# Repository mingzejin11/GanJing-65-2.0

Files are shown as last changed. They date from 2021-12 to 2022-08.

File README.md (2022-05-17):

# GanJing 65 rev 2.0
**A 65% keyboard with a rotary encoder, OLED screen and USB-c. Made using the Elite-c and through-hole components for easy soldering.**

[Bill of materials](https://octopart.com/bom-tool/jvwkTsDN)

## Layout options
The GanJing 65 PCB is hotswappable, supports ISO layouts, stepped caps lock, split right shift, and split spacebar options. There is also a soldered PCB available.

### Supported hotswap layouts
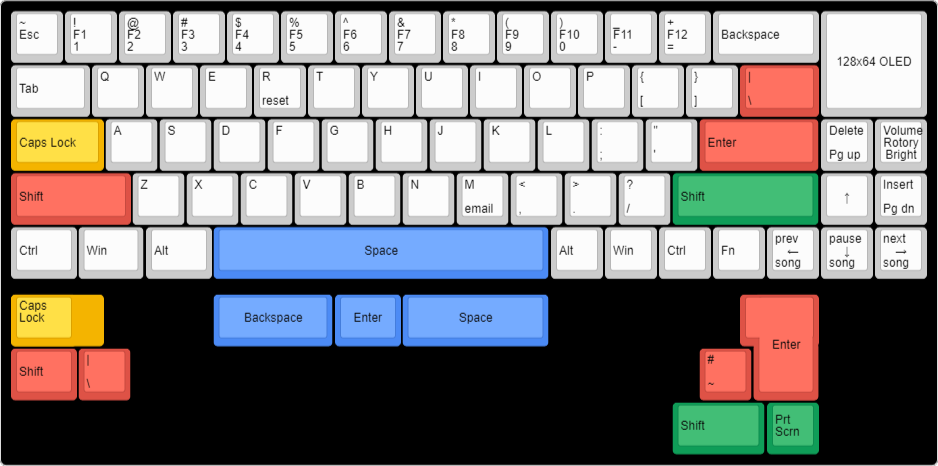
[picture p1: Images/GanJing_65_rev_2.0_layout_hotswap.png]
GanJing-65-2.0


## Hotswap PCB layout
### Front
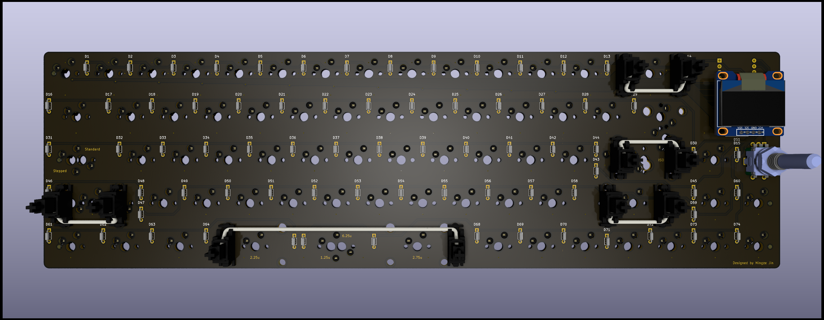
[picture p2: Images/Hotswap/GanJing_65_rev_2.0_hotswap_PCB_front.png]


### Back
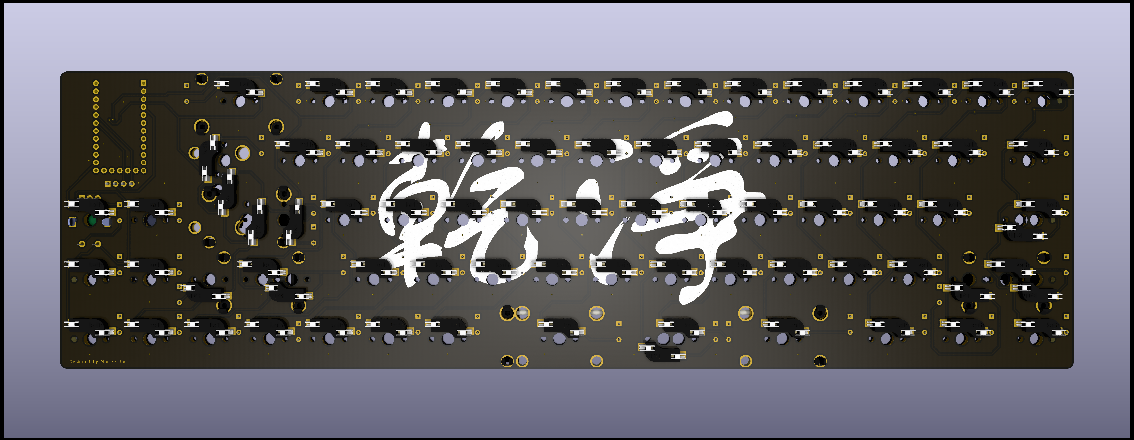
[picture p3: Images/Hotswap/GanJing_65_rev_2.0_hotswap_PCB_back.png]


## Hotswap PCB layout with exposed traces
### Front ANSI
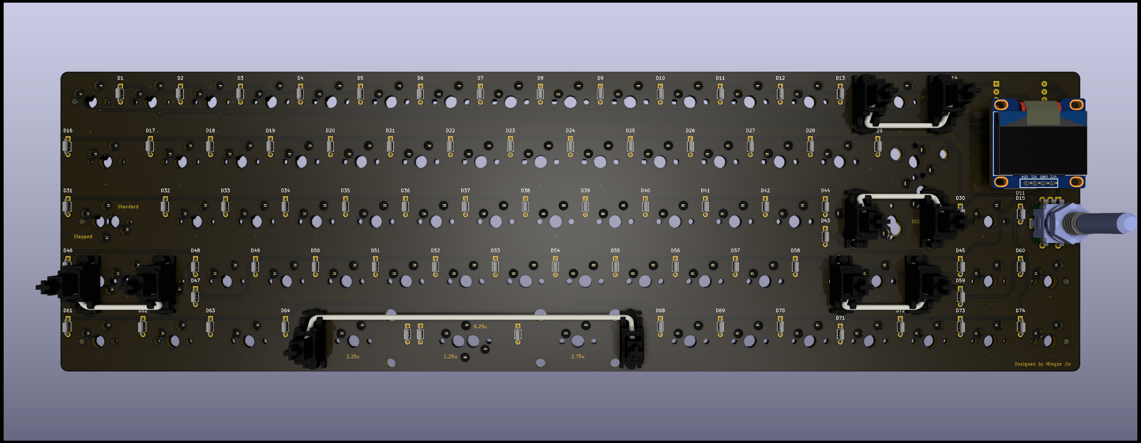
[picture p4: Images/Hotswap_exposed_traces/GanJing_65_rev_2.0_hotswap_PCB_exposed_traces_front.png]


### Front ISO and split spacebar
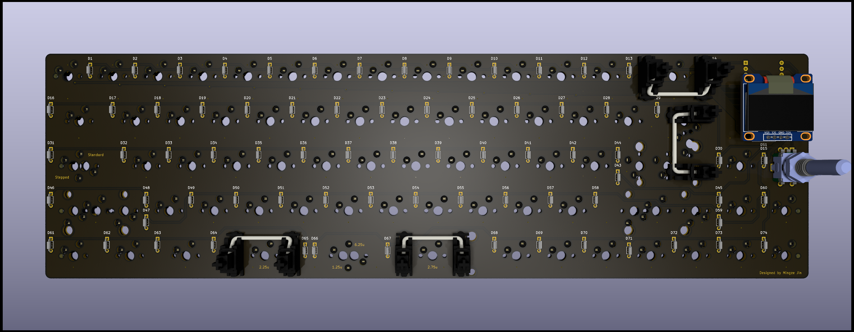
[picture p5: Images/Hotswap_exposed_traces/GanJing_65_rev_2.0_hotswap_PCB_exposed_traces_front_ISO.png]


### Back
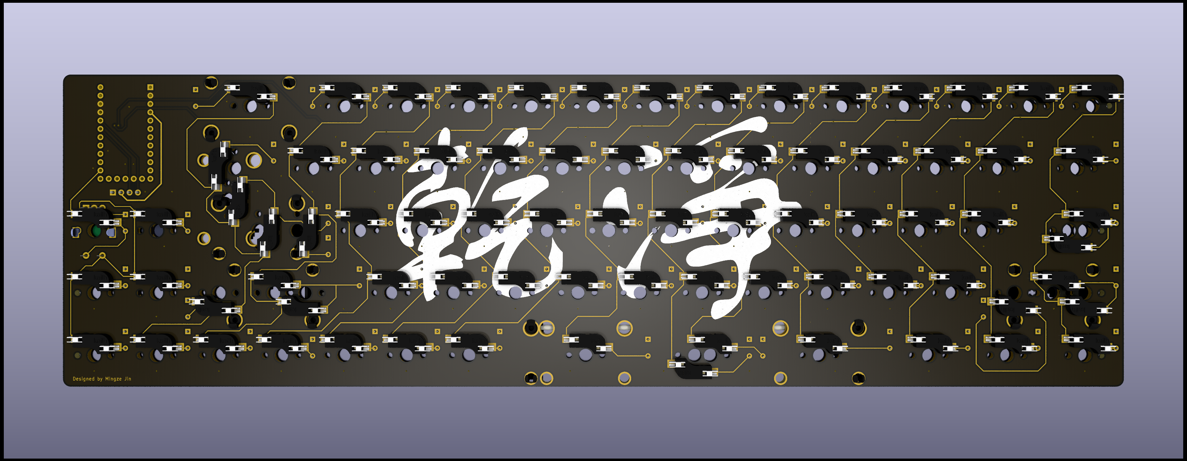
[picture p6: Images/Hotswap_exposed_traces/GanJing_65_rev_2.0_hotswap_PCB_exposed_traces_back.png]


### Supported solder layouts
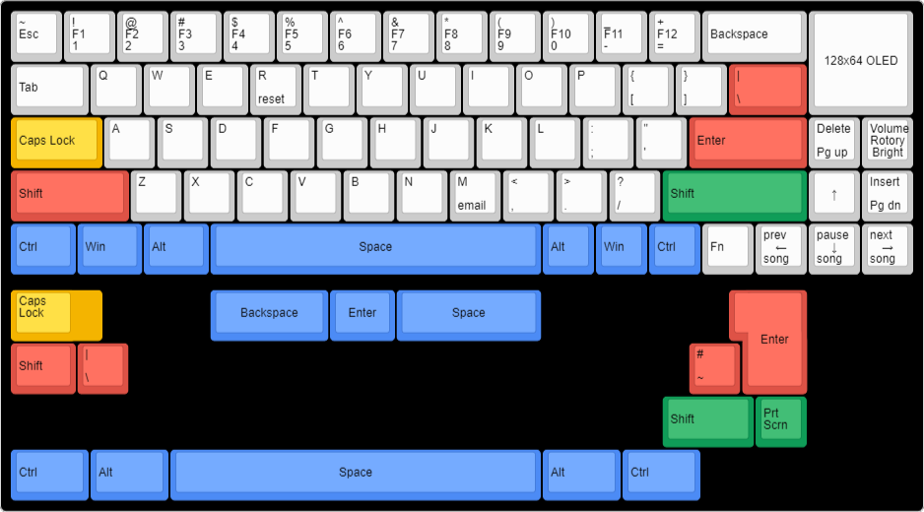
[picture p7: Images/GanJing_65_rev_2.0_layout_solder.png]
GanJing-65-2.0


## Solder PCB layout
### Front
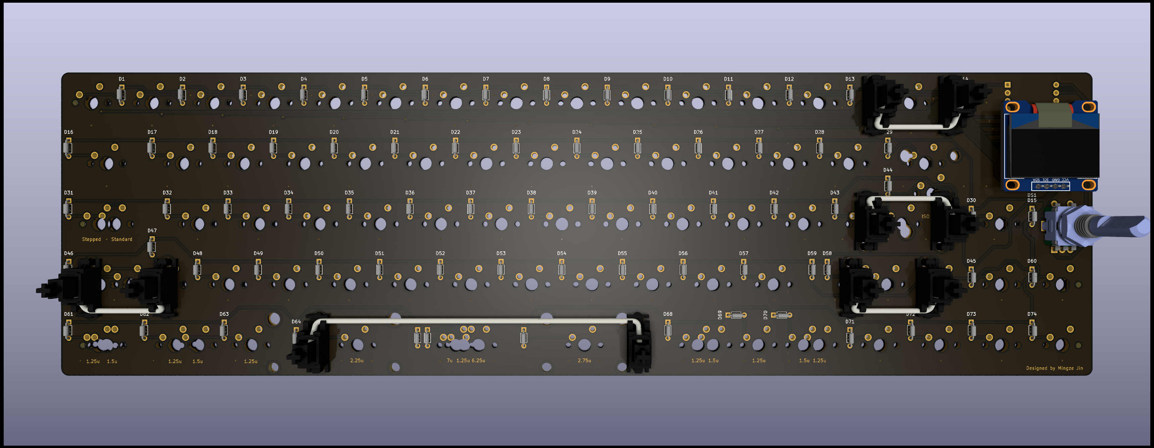
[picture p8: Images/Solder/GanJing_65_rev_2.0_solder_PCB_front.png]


### Front ISO and 7u spacebar
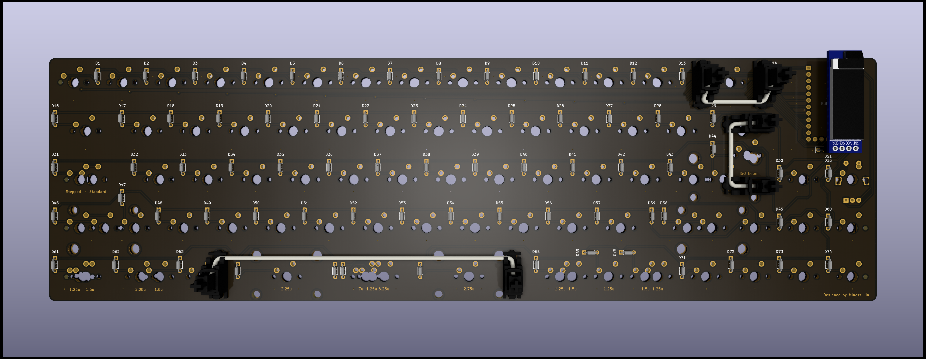
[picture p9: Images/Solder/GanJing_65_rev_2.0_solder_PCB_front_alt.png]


### Back
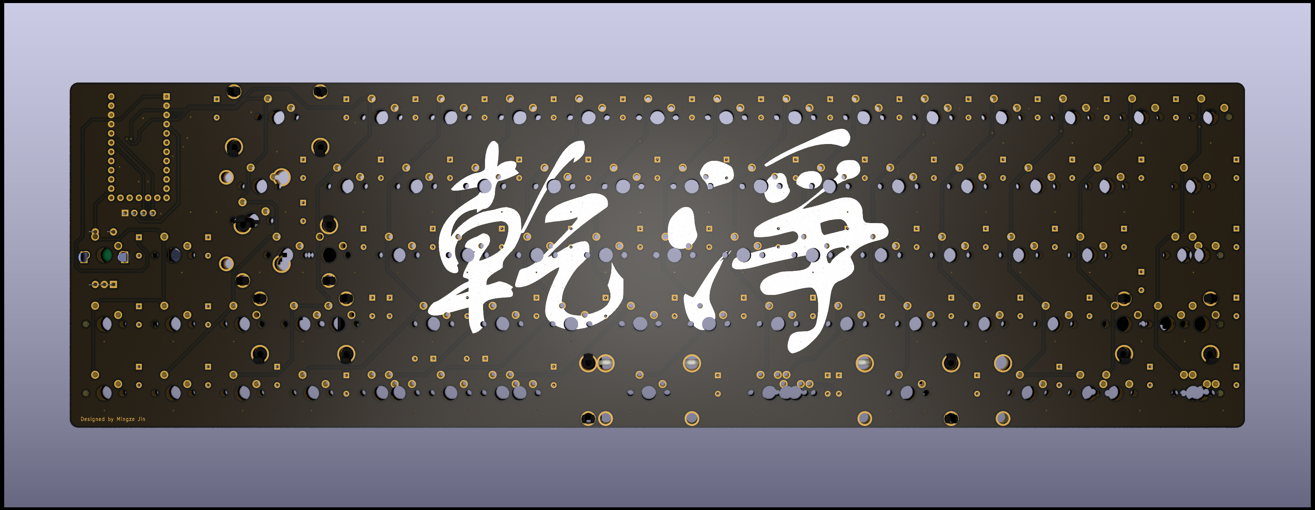
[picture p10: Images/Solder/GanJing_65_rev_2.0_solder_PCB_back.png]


## Schematic
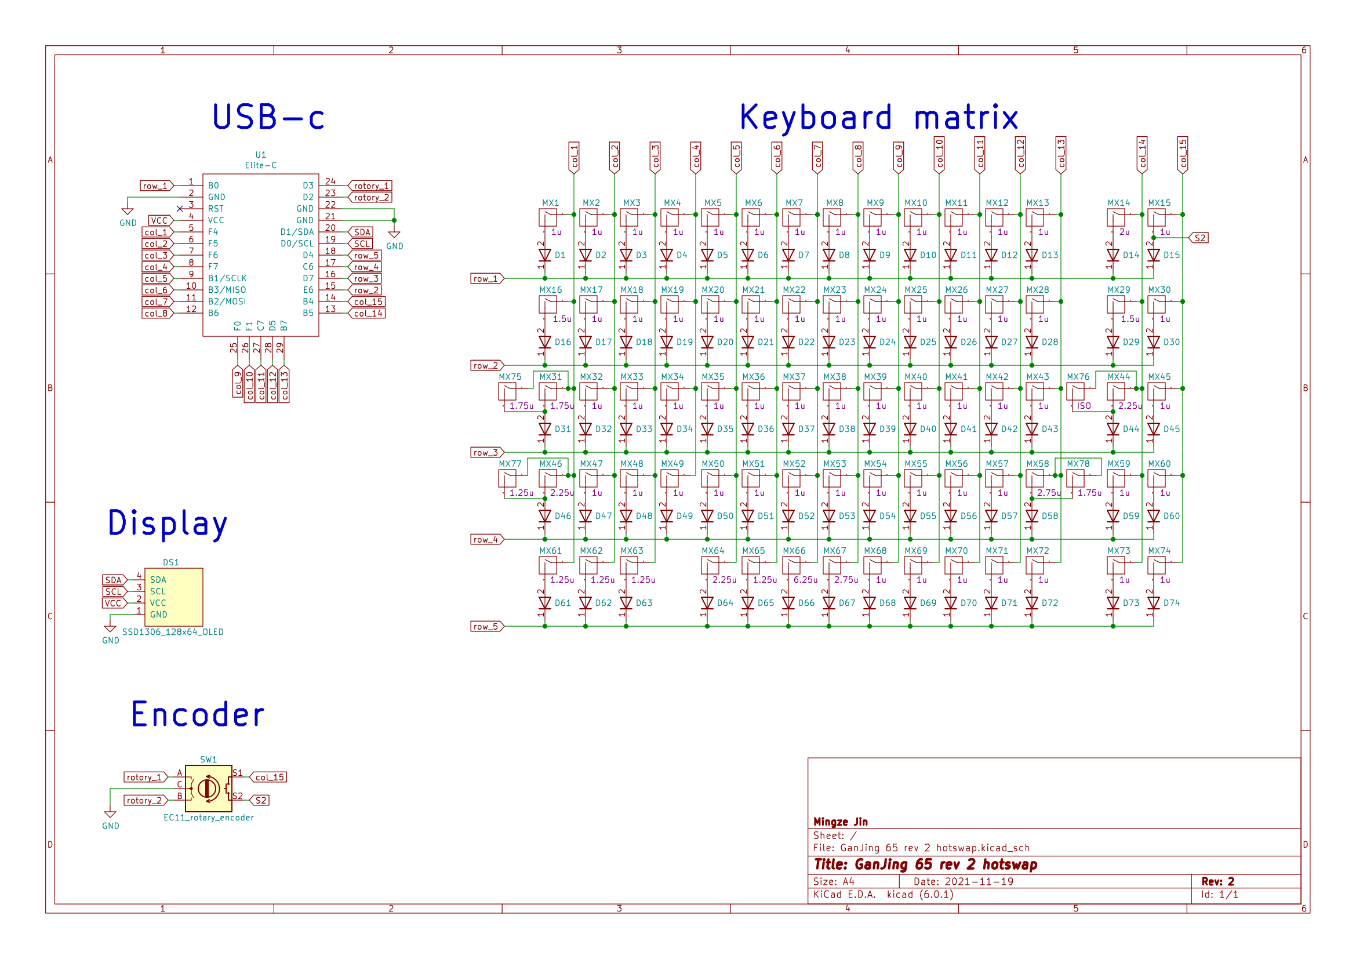
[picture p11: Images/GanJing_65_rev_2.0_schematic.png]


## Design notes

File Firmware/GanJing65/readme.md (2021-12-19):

# GanJing 70

GanJing 70

A 70% keyboard that can be assembled with only through hole components, including usb type-c and the Elite-C V4

* Keyboard Maintainer: [mingzejin11](https://github.com/mingzejin11)
* Hardware Supported: GanJing 70, atmega32u4
* Hardware Availability: [GitHub](https://github.com/mingzejin11/GanJing-65-2.0)

Make example for this keyboard (after setting up your build environment):

    make mingzejin11/GanJing65:default

Flashing example for this keyboard:

    make mingzejin11/GanJing65:default:flash

See the [build environment setup](https://docs.qmk.fm/#/getting_started_build_tools) and the [make instructions](https://docs.qmk.fm/#/getting_started_make_guide) for more information. Brand new to QMK? Start with our [Complete Newbs Guide](https://docs.qmk.fm/#/newbs).

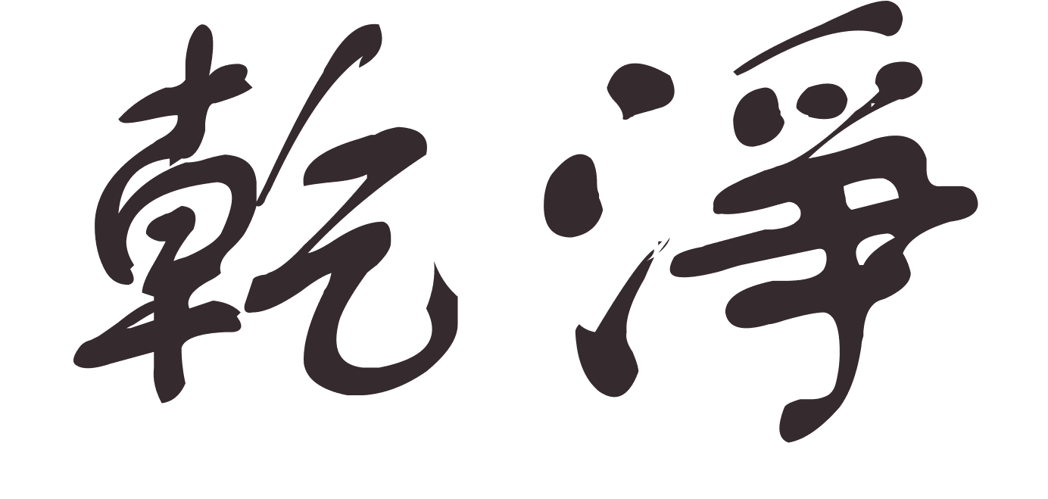
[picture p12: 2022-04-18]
Images/GanJing characters.png

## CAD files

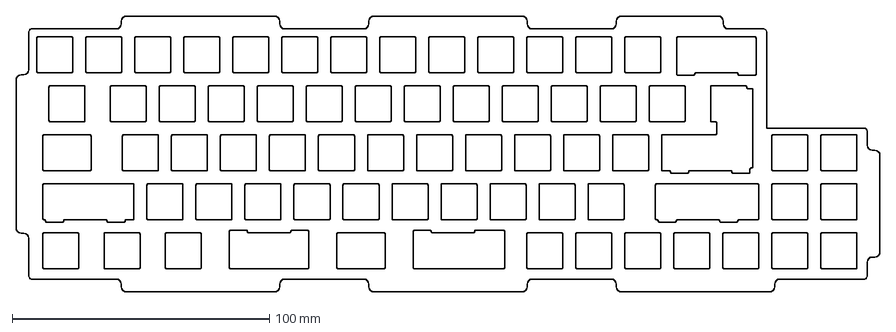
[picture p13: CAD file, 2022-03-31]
Case/Plate/GanJing 70 plate rev 2.dxf
335.8 x 107.2 mm

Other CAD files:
Case/GanJing 70 top.dwg
Case/4 3mm.dwg
Case/GanJing 70 plate rev 2.dwg
Case/2 4.5mm.dwg
Case/GanJing 70 middle gasket.dwg
Case/GanJing 70 middle open.dwg
Case/3 3mm.dwg
Case/GanJing 70 bottom.dwg
Case/1 3mm.dwg
Case/GanJing 70 middle closed.dwg

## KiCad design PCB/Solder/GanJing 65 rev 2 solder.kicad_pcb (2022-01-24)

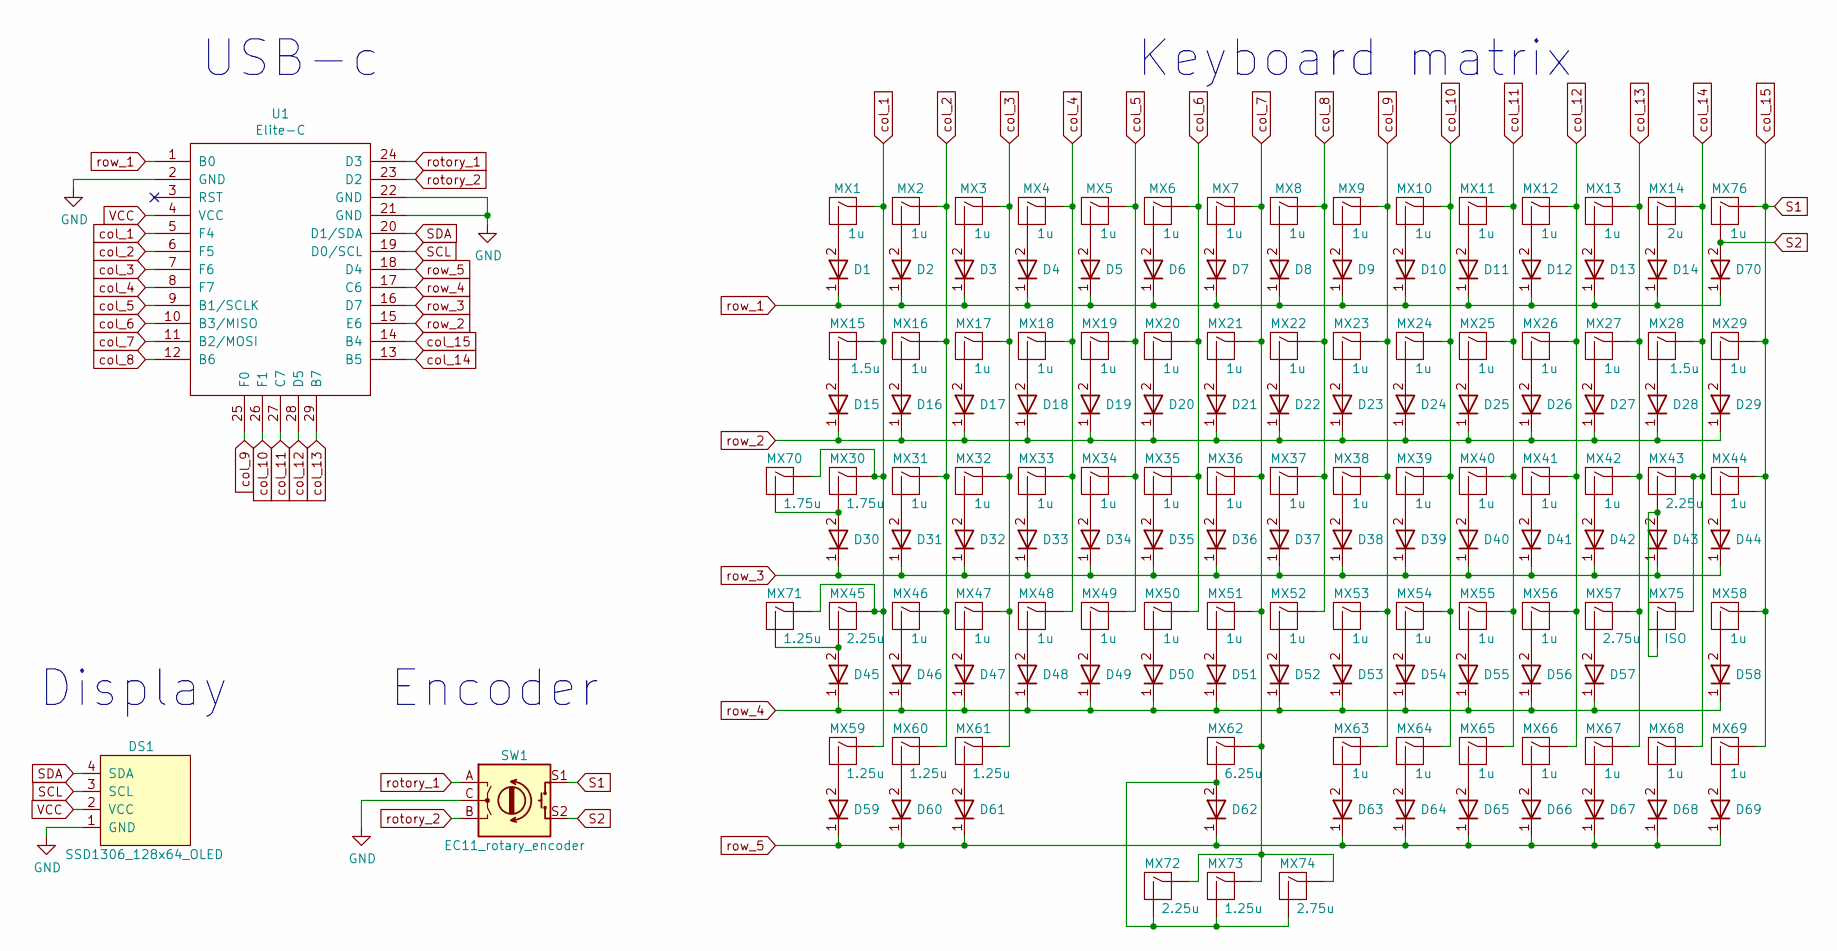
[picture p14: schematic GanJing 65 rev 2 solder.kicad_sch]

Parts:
D1, D2, D3, D4, D5, D6, D7, D8, D9, D10, D11, D12, D13, D14, D15, D16, D17, D18, D19, D20, D21, D22, D23, D24, D25, D26, D27, D28, D29, D30, D31, D32, D33, D34, D35, D36, D37, D38, D39, D40, D41, D42, D43, D44, D45, D46, D47, D48, D49, D50, D51, D52, D53, D54, D55, D56, D57, D58, D59, D60, D61, D62, D63, D64, D65, D66, D67, D68, D69, D70: 1N4148TR_diode
DS1: SSD1306_128x64_OLED
MX1, MX2, MX3, MX4, MX5, MX6, MX7, MX8, MX9, MX10, MX11, MX12, MX13, MX16, MX17, MX18, MX19, MX20, MX21, MX22, MX23, MX24, MX25, MX26, MX27, MX29, MX31, MX32, MX33, MX34, MX35, MX36, MX37, MX38, MX39, MX40, MX41, MX42, MX44, MX46, MX47, MX48, MX49, MX50, MX51, MX52, MX53, MX54, MX55, MX56, MX58, MX63, MX64, MX65, MX66, MX67, MX68, MX69, MX76: MX_1u_no_LED
MX14: MX_2u_no_LED
MX15, MX28: MX_1.5u_no_LED
MX30: MX_1.75u_no_LED
MX43, MX45: MX_2.25u_no_LED
MX57: MX_2.75u_no_LED
MX59, MX60, MX61, MX71, MX73: MX_1.25u_no_LED
MX62: MX_6.25u_no_LED_flipped_stabs
MX70: MX_1.75u_stepped_no_LED
MX72: MX_2.25u_no_LED_flipped_stabs
MX74: MX_2.75u_no_LED_flipped_stabs
MX75: MX_ISO_no_LED_flipped_stabs
SW1: EC11_rotary_encoder
U1: Elite-C

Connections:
GND: DS1.1 (GND), SW1.C, U1.2 (GND), U1.21 (GND), U1.22 (GND); also elsewhere on the board
unnamed: D1.2, MX1.2 (ROW)
unnamed: D2.2, MX2.2 (ROW)
unnamed: D3.2, MX3.2 (ROW)
unnamed: D4.2, MX4.2 (ROW)
unnamed: D5.2, MX5.2 (ROW)
unnamed: D6.2, MX6.2 (ROW)
unnamed: D7.2, MX7.2 (ROW)
unnamed: D8.2, MX8.2 (ROW)
unnamed: D9.2, MX9.2 (ROW)
unnamed: D10.2, MX10.2 (ROW)
unnamed: D11.2, MX11.2 (ROW)
unnamed: D12.2, MX12.2 (ROW)
unnamed: D13.2, MX13.2 (ROW)
unnamed: D14.2, MX14.2 (ROW)
unnamed: D15.2, MX15.2 (ROW)
unnamed: D16.2, MX16.2 (ROW)
unnamed: D17.2, MX17.2 (ROW)
unnamed: D18.2, MX18.2 (ROW)
unnamed: D19.2, MX19.2 (ROW)
unnamed: D20.2, MX20.2 (ROW)
unnamed: D21.2, MX21.2 (ROW)
unnamed: D22.2, MX22.2 (ROW)
unnamed: D23.2, MX23.2 (ROW)
unnamed: D24.2, MX24.2 (ROW)
unnamed: D25.2, MX25.2 (ROW)
unnamed: D26.2, MX26.2 (ROW)
unnamed: D27.2, MX27.2 (ROW)
unnamed: D28.2, MX28.2 (ROW)
unnamed: D29.2, MX29.2 (ROW)
unnamed: D30.2, MX30.2 (ROW), MX70.2 (ROW)
unnamed: D31.2, MX31.2 (ROW)
unnamed: D32.2, MX32.2 (ROW)
unnamed: D33.2, MX33.2 (ROW)
unnamed: D34.2, MX34.2 (ROW)
unnamed: D35.2, MX35.2 (ROW)
unnamed: D36.2, MX36.2 (ROW)
unnamed: D37.2, MX37.2 (ROW)
unnamed: D38.2, MX38.2 (ROW)
unnamed: D39.2, MX39.2 (ROW)
unnamed: D40.2, MX40.2 (ROW)
unnamed: D41.2, MX41.2 (ROW)
unnamed: D42.2, MX42.2 (ROW)
unnamed: D43.2, MX43.2 (ROW), MX75.2 (ROW)
unnamed: D44.2, MX44.2 (ROW)
unnamed: D45.2, MX45.2 (ROW), MX71.2 (ROW)
unnamed: D46.2, MX46.2 (ROW)
unnamed: D47.2, MX47.2 (ROW)
unnamed: D48.2, MX48.2 (ROW)
unnamed: D49.2, MX49.2 (ROW)
unnamed: D50.2, MX50.2 (ROW)
unnamed: D51.2, MX51.2 (ROW)
unnamed: D52.2, MX52.2 (ROW)
unnamed: D53.2, MX53.2 (ROW)
unnamed: D54.2, MX54.2 (ROW)
unnamed: D55.2, MX55.2 (ROW)
unnamed: D56.2, MX56.2 (ROW)
unnamed: D57.2, MX57.2 (ROW)
unnamed: D58.2, MX58.2 (ROW)
unnamed: D59.2, MX59.2 (ROW)
unnamed: D60.2, MX60.2 (ROW)
unnamed: D61.2, MX61.2 (ROW)
unnamed: D62.2, MX62.2 (ROW), MX72.2 (ROW), MX73.2 (ROW), MX74.2 (ROW)
unnamed: D63.2, MX63.2 (ROW)
unnamed: D64.2, MX64.2 (ROW)
unnamed: D65.2, MX65.2 (ROW)
unnamed: D66.2, MX66.2 (ROW)
unnamed: D67.2, MX67.2 (ROW)
unnamed: D68.2, MX68.2 (ROW)
unnamed: D69.2, MX69.2 (ROW)
S1: MX29.1 (COL), MX44.1 (COL), MX58.1 (COL), MX69.1 (COL), MX76.1 (COL), SW1.S1, U1.14 (B4); also elsewhere on the board
S2: D70.2, MX76.2 (ROW), SW1.S2; also elsewhere on the board
SCL: DS1.3 (SCL), U1.19 (D0/SCL)
SDA: DS1.4 (SDA), U1.20 (D1/SDA)
VCC: DS1.2 (VCC), U1.4 (VCC)
col_1: MX1.1 (COL), MX15.1 (COL), MX30.1 (COL), MX45.1 (COL), MX59.1 (COL), MX70.1 (COL), MX71.1 (COL), U1.5 (F4)
col_2: MX2.1 (COL), MX16.1 (COL), MX31.1 (COL), MX46.1 (COL), MX60.1 (COL), U1.6 (F5)
col_3: MX3.1 (COL), MX17.1 (COL), MX32.1 (COL), MX47.1 (COL), MX61.1 (COL), U1.7 (F6)
col_4: MX4.1 (COL), MX18.1 (COL), MX33.1 (COL), MX48.1 (COL), U1.8 (F7)
col_5: MX5.1 (COL), MX19.1 (COL), MX34.1 (COL), MX49.1 (COL), U1.9 (B1/SCLK)
col_6: MX6.1 (COL), MX20.1 (COL), MX35.1 (COL), MX50.1 (COL), U1.10 (B3/MISO)
col_7: MX7.1 (COL), MX21.1 (COL), MX36.1 (COL), MX51.1 (COL), MX62.1 (COL), MX72.1 (COL), MX73.1 (COL), MX74.1 (COL), U1.11 (B2/MOSI)
col_8: MX8.1 (COL), MX22.1 (COL), MX37.1 (COL), MX52.1 (COL), U1.12 (B6)
col_9: MX9.1 (COL), MX23.1 (COL), MX38.1 (COL), MX53.1 (COL), MX63.1 (COL), U1.25 (F0)
col_10: MX10.1 (COL), MX24.1 (COL), MX39.1 (COL), MX54.1 (COL), MX64.1 (COL), U1.26 (F1)
col_11: MX11.1 (COL), MX25.1 (COL), MX40.1 (COL), MX55.1 (COL), MX65.1 (COL), U1.27 (C7)
col_12: MX12.1 (COL), MX26.1 (COL), MX41.1 (COL), MX56.1 (COL), MX66.1 (COL), U1.28 (D5)
col_13: MX13.1 (COL), MX27.1 (COL), MX42.1 (COL), MX57.1 (COL), MX67.1 (COL), U1.29 (B7)
col_14: MX14.1 (COL), MX28.1 (COL), MX43.1 (COL), MX68.1 (COL), MX75.1 (COL), U1.13 (B5)
rotory_1: SW1.A, U1.24 (D3); also elsewhere on the board
rotory_2: SW1.B, U1.23 (D2); also elsewhere on the board
row_1: D1.1, D2.1, D3.1, D4.1, D5.1, D6.1, D7.1, D8.1, D9.1, D10.1, D11.1, D12.1, D13.1, D14.1, D70.1, U1.1 (B0)
row_2: D15.1, D16.1, D17.1, D18.1, D19.1, D20.1, D21.1, D22.1, D23.1, D24.1, D25.1, D26.1, D27.1, D28.1, D29.1, U1.15 (E6)
row_3: D30.1, D31.1, D32.1, D33.1, D34.1, D35.1, D36.1, D37.1, D38.1, D39.1, D40.1, D41.1, D42.1, D43.1, D44.1, U1.16 (D7)
row_4: D45.1, D46.1, D47.1, D48.1, D49.1, D50.1, D51.1, D52.1, D53.1, D54.1, D55.1, D56.1, D57.1, D58.1, U1.17 (C6)
row_5: D59.1, D60.1, D61.1, D62.1, D63.1, D64.1, D65.1, D66.1, D67.1, D68.1, D69.1, U1.18 (D4)

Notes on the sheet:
Keyboard matrix
Display
USB-c
Encoder

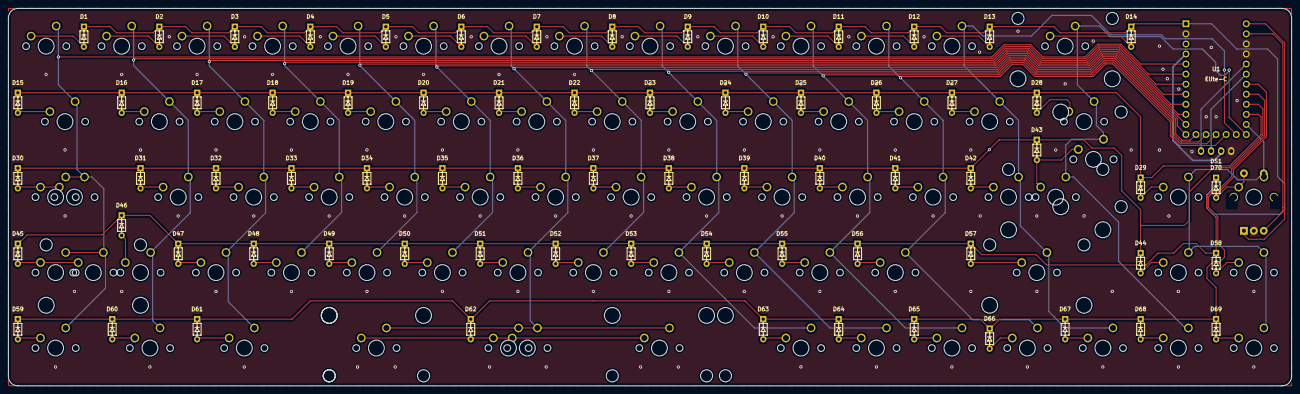
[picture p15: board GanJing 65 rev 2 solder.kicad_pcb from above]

Board: 2 copper layers, 323.8 x 95.2 mm, 149 parts (0 on the bottom side), 96 nets.

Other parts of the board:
SWe: EC11_rotary_encoder

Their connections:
GND: SWe.C; also elsewhere on the board
S1: SWe.S1; also elsewhere on the board
S2: SWe.S2; also elsewhere on the board
rotory_1: SWe.A; also elsewhere on the board
rotory_2: SWe.B; also elsewhere on the board

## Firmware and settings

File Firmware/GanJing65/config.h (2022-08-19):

/* Copyright 2021 mingzejin11
 * 
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
 * You should have received a copy of the GNU General Public License
 * along with this program.  If not, see <http://www.gnu.org/licenses/>.
*/

#pragma once

#include "config_common.h"

/* USB Device descriptor parameter */
#define VENDOR_ID       0x6B62
#define PRODUCT_ID      0x6869
#define DEVICE_VER      0x0002
#define MANUFACTURER    mingzejin11
#define PRODUCT         GanJing 70
#define DESCRIPTION     70% keyboard designed by Mingze Jin

/* Keyboard matrix size */
#define MATRIX_ROWS 5
#define MATRIX_COLS 15

/* Keyboard matrix pins */
#define MATRIX_ROW_PINS { B0, E6, D7, C6, D4 }
#define MATRIX_COL_PINS { F4, F5, F6, F7, B1, B3, B2, B6, F0, F1, C7, D5, B7, B5, B4 }
#define UNUSED_PINS

/* COL2ROW, ROW2COL*/
#define DIODE_DIRECTION COL2ROW

#define USB_MAX_POWER_CONSUMPTION 100

/* Encoder pad definition */
#define ENCODERS_PAD_A { D2 }
#define ENCODERS_PAD_B { D3 }
#define ENCODER_RESOLUTION 4

/* Enable the OLED driver */
#define OLED_DISPLAY_128X64
#define OLED_TIMEOUT 300000 // Measured in milliseconds = 5 minutes

/* Debounce reduces chatter (unintended double-presses) - set 0 if debouncing is not needed */
#define DEBOUNCE 5

/* Mechanical locking support. Use KC_LCAP, KC_LNUM or KC_LSCR instead in keymap */
#define LOCKING_SUPPORT_ENABLE
/* Locking resynchronize hack */
#define LOCKING_RESYNC_ENABLE

/* Always sends esc when ctrl is held to enable the task manager shortcut on Windows */
#define GRAVE_ESC_CTRL_OVERRIDE

/*
 * Force NKRO
 *
 * Force NKRO (nKey Rollover) to be enabled by default, regardless of the saved
 * state in the bootmagic EEPROM settings. (Note that NKRO must be enabled in the
 * makefile for this to work.)
 *
 * If forced on, NKRO can be disabled via magic key (default = LShift+RShift+N)
 * until the next keyboard reset.
 *
 * NKRO may prevent your keystrokes from being detected in the BIOS, but it is
 * fully operational during normal computer usage.
 *
 * For a less heavy-handed approach, enable NKRO via magic key (LShift+RShift+N)
 * or via bootmagic (hold SPACE+N while plugging in the keyboard). Once set by
 * bootmagic, NKRO mode will always be enabled until it is toggled again during a
 * power-up.
 *
 */
//#define FORCE_NKRO

/*
 * Feature disable options
 *  These options are also useful to firmware size reduction.
 */

/* disable debug print */
//#define NO_DEBUG

/* disable print */
//#define NO_PRINT

/* disable action features */
//#define NO_ACTION_LAYER
//#define NO_ACTION_TAPPING
//#define NO_ACTION_ONESHOT
//#define NO_ACTION_MACRO
//#define NO_ACTION_FUNCTION

/* Bootmagic Lite key configuration */
#define BOOTMAGIC_LITE_ROW 0
#define BOOTMAGIC_LITE_COLUMN 0

// To save on firmware size lol
#ifndef NO_DEBUG
    #define NO_DEBUG
#endif // !NO_DEBUG

#if !defined(NO_PRINT) && !defined(CONSOLE_ENABLE)
    #define NO_PRINT
#endif // !NO_PRINT

#define NO_ACTION_MACRO
#define NO_ACTION_FUNCTION

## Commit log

2021-11-21 Initial placement
    [GanJing 65 rev 2.kicad_pcb, GanJing 65 rev 2.sch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]
2021-11-25 Initial routing
    [GanJing 65 rev 2.kicad_pcb]
2021-12-04 Finished routing
    [GanJing 65 rev 2-B_Cu.gbr, GanJing 65 rev 2-B_Mask.gbr, GanJing 65 rev 2-B_Paste.gbr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]
2021-12-05 Adding images and optional key switch instead of rotory knob
    [GanJing 65 rev 2-B_Cu.gbr, GanJing 65 rev 2-B_Mask.gbr, GanJing 65 rev 2-B_Paste.gbr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]
2021-12-05 Cleaning up some routing
    [GanJing 65 rev 2-B_Cu.gbr, GanJing 65 rev 2-B_Mask.gbr, GanJing 65 rev 2-B_Paste.gbr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]
2021-12-05 Changing F mask cuz I'm a dumbass lol
    [GanJing 65 rev 2-B_Cu.gbr, GanJing 65 rev 2-B_Mask.gbr, GanJing 65 rev 2-B_Paste.gbr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]
2021-12-05 Updating gerbers
2021-12-07 Created a hotswap version
    [GanJing 65 rev 2 hotswap-B_Cu.gbr, GanJing 65 rev 2 hotswap-B_Mask.gbr, GanJing 65 rev 2 hotswap-B_Paste.gbr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]
2021-12-07 Adding new images
    [GanJing 65 rev 2 hotswap.kicad_pcb]
2021-12-07 Adding firmware and case files
    [GanJing-65-bottom.dxf, GanJing-65-closed-layer.dxf, GanJing-65-foot-1.dxf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]
2021-12-14 Adding split spacebar to hotswap PCB
    [GanJing 65 rev 2 hotswap-B_Cu.gbr, GanJing 65 rev 2 hotswap-B_Mask.gbr, GanJing 65 rev 2 hotswap-B_Paste.gbr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]
2021-12-19 Writing the firmware is fun
    [GanJing 65 rev 2 solder-B_Cu.gbr, GanJing 65 rev 2 solder-B_Mask.gbr, GanJing 65 rev 2 solder-B_Paste.gbr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]
2021-12-21 finished firmware
    [GanJing 65 rev 2 solder-B_Cu.gbr, GanJing 65 rev 2 solder-B_Mask.gbr, GanJing 65 rev 2 solder-B_Paste.gbr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]
2021-12-21 Fixing hotswap PCB traces
    [GanJing 65 rev 2 hotswap-B_Cu.gbr, GanJing 65 rev 2 hotswap-B_Mask.gbr, GanJing 65 rev 2 hotswap-B_Paste.gbr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]
2022-01-11 Updated PCBs to adjust the location of the encoder plus fix routing errors in the hotswap version. Plate file is also completed, case files still need to be finalized
    [GanJing 65 rev 2 hotswap-B_Cu.gbr, GanJing 65 rev 2 hotswap-B_Mask.gbr, GanJing 65 rev 2 hotswap-B_Paste.gbr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]
2022-01-24 Switching to KiCad 6.0.1 so some files have been converted and the component symbol library files has been converted from .lib to .kicad_sym
    [GanJing 65 rev 2 hotswap.kicad_pcb, GanJing 65 rev 2 hotswap.kicad_sch, GanJing 65 rev 2 solder.kicad_pcb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]
2022-01-26 Case files completed
    [GanJing 70 bottom.dwg, GanJing 70 bottom.dxf, GanJing 70 middle closed.dwg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]
2022-01-28 Updating plate file
    [GanJing 70 plate rev 1.dwg, GanJing 70 plate rev 2.dxf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]
2022-01-28 Adding extra screw hole for stability and fixing foot piece
    [GanJing 70 bottom.dwg, GanJing 70 middle closed.dwg, GanJing 70 middle gasket.dwg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]
2022-01-31 Updating case to 10mm boarders
    [GanJing 70 bottom.dwg, GanJing 70 middle closed.dwg, GanJing 70 middle gasket.dwg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]
2022-02-04 Updating the CAD files to all be 0.00mm
    [GanJing 70 bottom.dwg, GanJing 70 middle closed.dwg, GanJing 70 middle gasket.dwg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]
2022-02-04 Fixing plate space bar
    [GanJing 70 plate rev 2.dwg]
2022-02-08 Adding a bunch of different layout options to the hotswap board
    [GanJing 65 rev 2 hotswap-B_Cu.gbr, GanJing 65 rev 2 hotswap-B_Mask.gbr, GanJing 65 rev 2 hotswap-B_Paste.gbr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]
2022-02-09 Updating plate tolerances
    [GanJing 65 rev 2 hotswap-B_Cu.gbr, GanJing 65 rev 2 hotswap-B_Mask.gbr, GanJing 65 rev 2 hotswap-B_Paste.gbr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]
2022-02-20 Updating PCB and firmware
    [GanJing 65 rev 2 hotswap-B_Cu.gbr, GanJing 65 rev 2 hotswap-B_Mask.gbr, GanJing 65 rev 2 hotswap-B_Paste.gbr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]
2022-02-27 Adding cutting files
    [1 3mm.dwg, 2 4.5mm.dwg, 3 3mm.dwg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]
2022-03-09 Adding new gasket strips
    [2 4.5mm.dwg, 3 3mm.dwg, GanJing 70 bottom.dwg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]
2022-03-31 Updating plate to support split shift key on the right side
    [GanJing 70 plate rev 2.dwg, GanJing 70 plate rev 2.dxf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]
2022-04-18 Adding 3d models and flipping the right shift stabilizers to reduce interference
    [GanJing 65 rev 2 hotswap-B_Cu.gbr, GanJing 65 rev 2 hotswap-B_Mask.gbr, GanJing 65 rev 2 hotswap-B_Paste.gbr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]
2022-04-18 Adding option to have switch instead of knob
    [GanJing 65 rev 2 hotswap-B_Cu.gbr, GanJing 65 rev 2 hotswap-B_Mask.gbr, GanJing 65 rev 2 hotswap-B_Paste.gbr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]
2022-04-19 Updating soldered version
    [GanJing 65 rev 2 hotswap exposed traces-B_Cu.gbr, GanJing 65 rev 2 hotswap exposed traces-B_Mask.gbr, GanJing 65 rev 2 hotswap exposed traces-B_Paste.gbr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]
2022-04-19 Updating top case file
    [4 3mm.dwg, GanJing 70 top.dwg]
2022-05-15 Updating gerbers and sodlered PCB
    [GanJing 65 rev 2 hotswap exposed traces-B_Cu.gbr, GanJing 65 rev 2 hotswap exposed traces-B_Mask.gbr, GanJing 65 rev 2 hotswap exposed traces-B_Paste.gbr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]
2022-05-15 updating soldered pcb to have logo graphic
    [GanJing 65 rev 2 solder-B_Cu.gbr, GanJing 65 rev 2 solder-B_Mask.gbr, GanJing 65 rev 2 solder-B_Paste.gbr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]
2022-05-17 Making minor trace edits to all three versions of PCB
    [GanJing 65 rev 2 hotswap exposed traces-B_Cu.gbr, GanJing 65 rev 2 hotswap exposed traces-B_Mask.gbr, GanJing 65 rev 2 hotswap exposed traces-B_Paste.gbr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]
2022-05-17 Adding 7u to soldered PCB
    [GanJing 65 rev 2 solder-B_Cu.gbr, GanJing 65 rev 2 solder-B_Mask.gbr, GanJing 65 rev 2 solder-B_Paste.gbr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]
2022-05-17 Adding rounded pcbs
    [GanJing 65 rev 2 hotswap-B_Cu.gbr, GanJing 65 rev 2 hotswap-B_Mask.gbr, GanJing 65 rev 2 hotswap-B_Paste.gbr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]

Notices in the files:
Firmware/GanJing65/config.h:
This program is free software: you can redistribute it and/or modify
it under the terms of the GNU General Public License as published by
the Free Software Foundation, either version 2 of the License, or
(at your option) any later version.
